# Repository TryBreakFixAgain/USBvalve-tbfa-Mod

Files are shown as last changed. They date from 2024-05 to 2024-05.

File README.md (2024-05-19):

### *USBvalve TBFA Mod*

Based on [cecio/USBvalve](https://github.com/cecio/USBvalve) Version 0.18.0

[**For basic information, please visit the cecio repository.**](https://github.com/cecio/USBvalve)

<br>

I made some modifications to the USBvalve to fulfil the needs of my friends and myself.<br>
To enable **SD-Card Logging**, the entire serial output was redirected.<br>
In addition, there is the comfortable indication via a Ws2812b LED in a **Traffic Light System**.<br>
Additional you can create an independent system with a **Pimoroni Pico Lipo** and the LiPo-Mod.<br>
To ensure complete wireless debugging, the **WiFi HTML Output ESP-01 Mod** is used.<br>
As the PicoW unfortunately does not provide enough RAM, an ESP01 takes over the server tasks.<br>
<br>
Compatibility with the Pi Pico Watch has been removed.

I decided against a custom PCB and used standard components.

**All required parts can be found in the corresponding BOM.**

**You can find pictures in the pictures folder.**
<br>
<br>
**Table of Contents**
* [Mods](#mods)
* [Cases](#cases)
* [Pico Pinout](#pico-pinout)
* [Mappings No Lipo](#mappings-no-lipo)
* [Mappings Pimoroni Pico LiPo](#mappings-lipo-pimoroni-pico-lipo)
* [Additional Mappings SD-Logger](#mappings-sd-logger)
* [Additional Mappings ESP01-Server](#mappings-esp01-server)
* [LED meanings](#led-meanings)
* [Firmware Naming](#firmware-naming)
* [Customize Firmware](#customize-firmware)
* [Dockerfile](#dockerfile)
* [Flash Firmware](#flash-firmware)
* [Safety Warning](#safety-warning)

<br><br>

### *Mods:*
- TrafficLight LED
- simple language customisation
- Fixing the first 2 lines
- LiPo Mod
- SD-Card Logger
- WiFi HTML Output ESP-01 (ESP8266)
- PicoW LED Fix (No-WiFi Support)

**More information can be found on the wiki**

<br><br>

### *Cases:*
STL-Files could be fond in the STL folder.

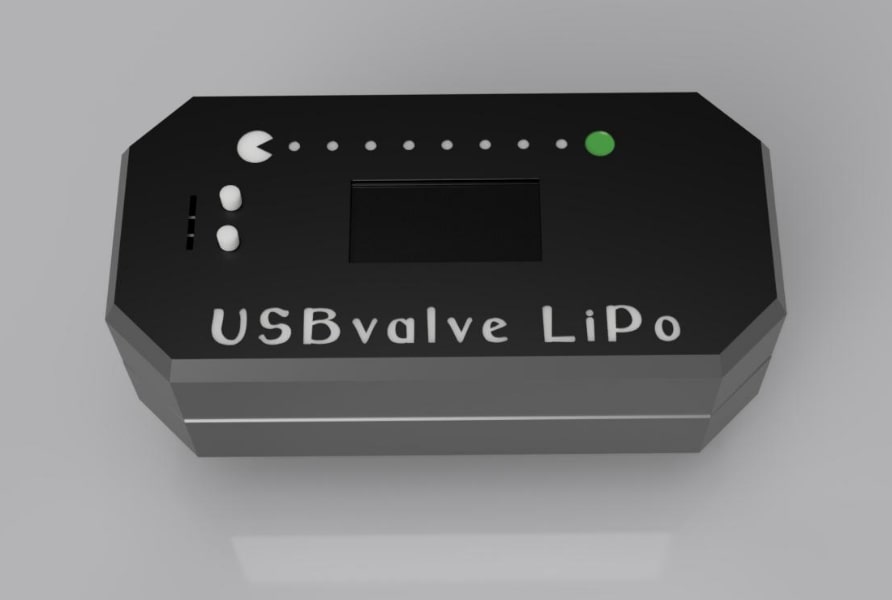
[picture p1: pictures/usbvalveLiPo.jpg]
USBvalve LiPo
> 
> 
> **3D printable case for USBvalve LiPo (FDM ready 0.4 Nozzle)**
> <details> 
> <summary>My Settings</summary> 
>  
> **LipoValveBottom.stl & LipoValveBottom.stl**
> 
> - No supports
> - Layer height first and secound Layer 0.1 after it 0.2
> 
> **LipoValveInner.stl**
> 
> - Supports
> - Layer height 0.2
> 
> **2x LipoValveButton.stl**
> 
> - No supports
> - Raft
> - Layer height 0.2
>  
> </details>

<br>
  
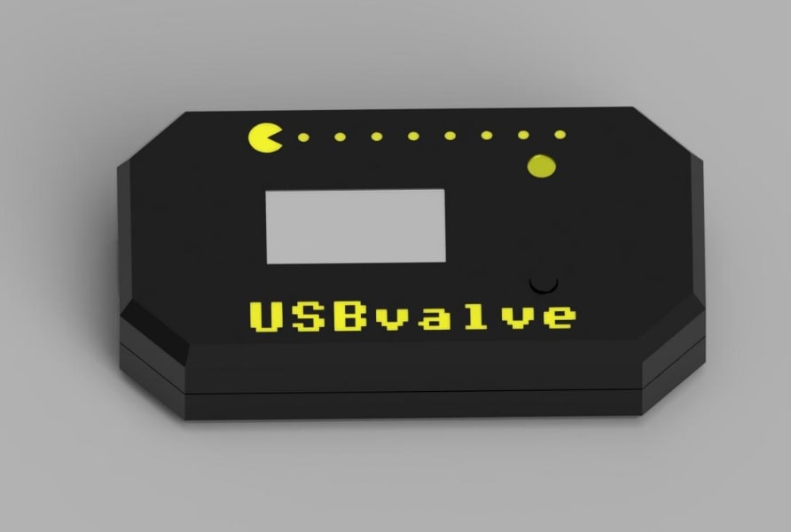
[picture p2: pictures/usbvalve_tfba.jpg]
USBvalve tbfa
>
> 
> **3D printable case for USBvalve none custom PCB (FDM ready 0.4 Nozzle)**
> <details> 
> <summary>My Settings</summary> 
>  
> - No supports
> - Layer height first and secound Layer 0.1 after it 0.2
>
> </details>

<br><br>
### *Pico Pinout:*
USBvalve tbfa
<br><br>

### *Mappings NO LiPo:*
> - PIN6 (GPIO4) of Pi --> OLED SDA
> - PIN7 (GPIO5) of Pi --> OLED SCL
> - PIN19 (GPIO14) of Pi --> D+ of USB Host
> - PIN20 (GPIO15) of Pi --> D- of USB Host
> - PIN23 (GND) of Pi --> GND of USB Host
> - PIN38 (GND) of Pi --> OLED GND
> - PIN36 (3V3OUT) of Pi --> OLED VCC
> - PIN40 (VBUS) of Pi --> VCC of USB Host
>   
> TrafficLight
> I use 3.3V to power the LED because 5V was too bright for me.
> Depending on the LED you may have to use 5V.
> 
> - PIN36 (3V3OUT) of Pi --> OLED VCC OR PIN40 (VBUS) of Pi --> VCC of Ws2812b DOT
> - PIN28 (GND) of Pi --> GND of Ws2812b DOT
> - PIN10 (GPIO7) of Pi --> DIN of Ws2812b DOT
>  
> Additional BOOTSEL Button form my Case Design
> - TP6 of Pi (Bottom side Testpoint) --> Pushbutton
> - PIN28 (GND) of Pi --> Pushbutton
> 

<br><br>
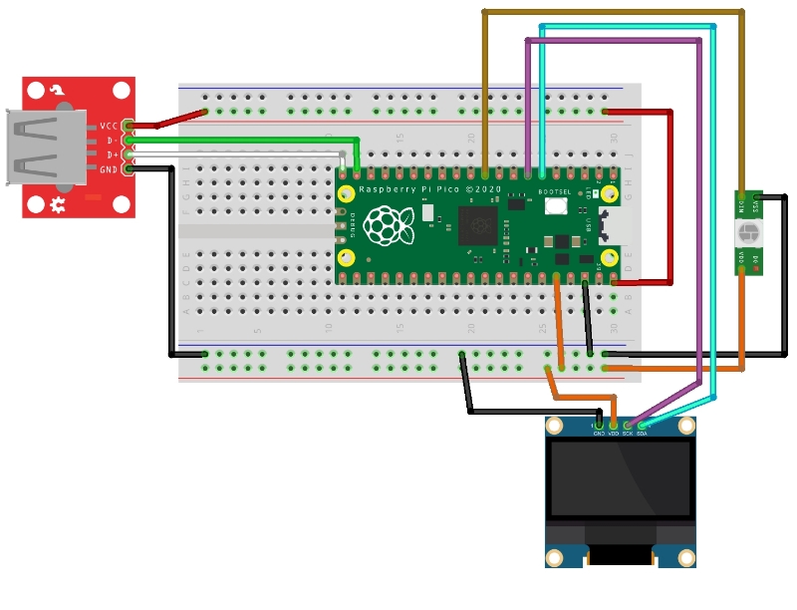
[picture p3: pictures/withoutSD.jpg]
USBvalve tbfa without SD

<br><br>

### *Mappings LiPo (Pimoroni Pico LiPo):*
> - PIN6 (GPIO4) of Pi --> OLED SDA
> - PIN7 (GPIO5) of Pi --> OLED SCL
> - PIN19 (GPIO14) of Pi --> D+ of USB Host
> - PIN20 (GPIO15) of Pi --> D- of USB Host
> - PIN38 (GND) of Pi --> OLED GND
> - PIN36 (3V3OUT) of Pi --> OLED VCC
> - PIN39 (VSYS) of Pi --> + IN DC-DC  3.7V to 5V Step-Up
> - PIN23 (GND) of Pi --> - IN DC-DC  3.7V to 5V Step-Up
> - \+ OUT DC-DC  3.7V to 5V Step-Up --> VCC of USB Host
> - \- OUT DC-DC  3.7V to 5V Step-Up --> GND of USB Host
>   
> TrafficLight
> I use 3.3V to power the LED because 5V was too bright for me.
> Depending on the LED you may have to use 5V.
> 
> - PIN36 (3V3OUT) of Pi --> OLED VCC OR PIN40 (VBUS) of Pi --> VCC of Ws2812b DOT
> - PIN28 (GND) of Pi --> GND of Ws2812b DOT
> - PIN10 (GPIO7) of Pi --> DIN of Ws2812b DOT
> 

<br><br>

### *Mappings SD-Logger:*
> SPI MicroSD Breakout Adapter
>
> - PIN21 (GPIO16) of Pi --> SD-Card Breakout MISO 
> - PIN22 (GPIO17) of Pi --> SD-Card Breakout CS
> - PIN24 (GPIO18) of Pi --> SD-Card Breakout SCK
> - PIN25 (GPIO19) of Pi --> SD-Card Breakout MOSI
> - PIN33 (GND) of Pi --> OLED GND
> - PIN36 (3V3OUT) of Pi --> OLED VCC
> 

<br><br>
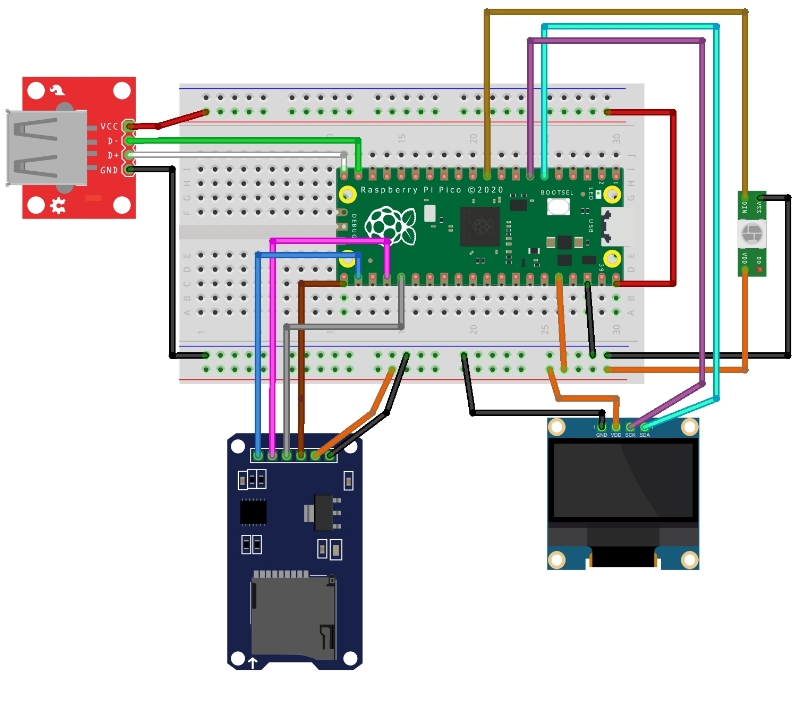
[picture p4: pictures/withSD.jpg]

<br><br>

<br><br>

### *Mappings ESP01-Server:*
> ESP01 (ESP8266) Server
>
> - PIN11 (GPIO8) of Pi --> RX of ESP01 
> - PIN12 (GPIO9) of Pi --> TX of ESP01 
> - PIN18 (GND) of Pi --> GND  of ESP01
> - PIN36 (3V3OUT) of Pi --> 3.3 VCC of ESP01
> - Push Button --> GPIO0 of ESP01 
> - Push Button --> PIN18 (GND) of Pi
>

<br><br>
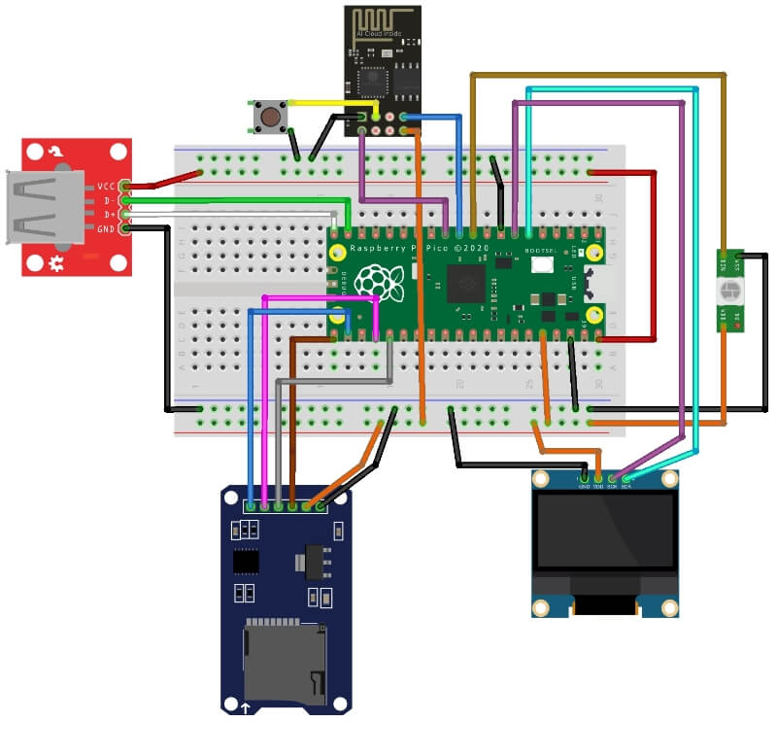
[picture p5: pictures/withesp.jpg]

<br><br>

### *LED meanings:*
- Red: Things are happening that must not happen.
- Green: Everything is OK
- Orange: Attention, something could be wrong.
- Off: Nothing connected or nothing recognised. Attention: The LED remains off with some RubberDuckies. So if a stick is connected and the LED shows nothing, it could be a RubberDucky.

<br><br>

### *Firmware Naming:*
>
>USBvalve_tbfa-x.xx.x-32NoMod = No Mods, 32Pixel Display<br>
>USBvalve_tbfa-x.xx.x-64NoMod = No Mods, 64Pixel Display
>
>USBvalve_tbfa-x.xx.x-32Tr = TrafficLight, 32Pixel Display<br>
>USBvalve_tbfa-x.xx.x-64Tr = TrafficLight, 64Pixel Display
>
>USBvalve_tbfa-x.xx.x-32SdTr = SD-Logger, TrafficLight, 32Pixel Display<br>
>USBvalve_tbfa-x.xx.x-64SdTr = SD-Logger, TrafficLight, 64Pixel Display
>
>USBvalve_tbfa-x.xx.x-32Sd = SD-Logger, 32Pixel Display<br>
>USBvalve_tbfa-x.xx.x-64Sd = SD-Logger, 64Pixel Display
>
>USBvalve_tbfa-x.xx.x-32LiSdTr = LiPo, SD-Logger, TrafficLight, 32Pixel Display<br>
>USBvalve_tbfa-x.xx.x-64LiSdTr = LiPo, SD-Logger, TrafficLight, 64Pixel Display
>
>USBvalve_tbfa-x.xx.x-32LiSd = LiPo, SD-Logger, 32Pixel Display<br>
>USBvalve_tbfa-x.xx.x-64LiSd = LiPo, SD-Logger, 64Pixel Display
>
>USBvalve_tbfa-x.xx.x-32LiTr = LiPo, TrafficLight, 32Pixel Display<br>
>USBvalve_tbfa-x.xx.x-64LiTr = LiPo, TrafficLight, 64Pixel Display
>
>USBvalve_tbfa-x.xx.x-32Li = LiPo, 32Pixel Display<br>
>USBvalve_tbfa-x.xx.x-64Li = LiPo, 32Pixel Display
>
>USBvalve_tbfa-x.xx.x-32Wi = WiFi, 32Pixel Display<br>
>USBvalve_tbfa-x.xx.x-64Wi = WiFi, 64Pixel Display
>
>USBvalve_tbfa-x.xx.x-32SdTrWI = SD-Logger, TrafficLight, WiFi, 32Pixel Display<br>
>USBvalve_tbfa-x.xx.x-64SdTrWI = SD-Logger, TrafficLight, WiFi, 64Pixel Display
>
>USBvalve_tbfa-x.xx.x-32SdWI = SD-Logger, WiFi, 32Pixel Display<br>
>USBvalve_tbfa-x.xx.x-64SdWI = SD-Logger, WiFi, 64Pixel Display
>
>USBvalve_tbfa-x.xx.x-32LiSdTrWI = LiPo, SD-Logger, TrafficLight, WiFi, 32Pixel Display<br>
>USBvalve_tbfa-x.xx.x-64LiSdTrWI = LiPo, SD-Logger, TrafficLight, WiFi, 64Pixel Display
>
>USBvalve_tbfa-x.xx.x-32LiSdWI = LiPo, SD-Logger, WiFi, 32Pixel Display<br>
>USBvalve_tbfa-x.xx.x-64LiSdWI = LiPo, SD-Logger, WiFi, 64Pixel Display
>
>USBvalve_tbfa-x.xx.x-32LiTrWI = LiPo, TrafficLight, WiFi, 32Pixel Display<br>
>USBvalve_tbfa-x.xx.x-64LiTrWI = LiPo, TrafficLight, WiFi, 64Pixel Display
>
>USBvalve_tbfa-x.xx.x-32LiWI = LiPo, WiFi, 32Pixel Display<br>
>USBvalve_tbfa-x.xx.x-64LiWI = LiPo, WiFi, 32Pixel Display
>

<br><br>
### *Customize Firmware:*
You can build your own firmware.

**Uncomment one ore more defines to compile the MODS you want to use.**
```
/* 
 * #define TBFA_TRAFFIC = TrafficLight Mod
 * #define TBFA_LIPO = Pimoroni Pico LiPo Battery Mod
 * #define TBFA_SDLOG = SD-CARD Logger Mod
 * #define TBFA_ONBORDLED = Use Onbord LED on Pico
 * #define TBFA_ONBORDLEDW = Use Onbord LED on PicoW
 * #define TBFA_ESP01SRV = Use ESP01 as Webserver
 */

//#define TBFA_TRAFFIC
//#define TBFA_LIPO
//#define TBFA_SDLOG
//#define TBFA_ONBORDLED
//#define TBFA_ONBORDLEDW
//#define TBFA_ESP01SRV
```
<br>
To build the standard one I used:

- Arduino IDE 2.3.2
- Adafruit TinyUSB Library version 3.1.4, Pico-PIO-USB version 0.5.2, Board Raspberry Pi RP2040 (3.8.0) setting Tools=>CPU Speed at 120MHz and Tools=>USB Stack to Adafruit TinyUSB
- Adafruit_SSD1306 OLED library version 2.5.10
- ArduinoJson 7.0.4
- Adafruit NeoPixel 1.12.2
- SD by Arduino, Sparkfun 1.2.4

**Information on customising the ESP01 firmware can be found in the wiki**

<br><br>

### *Dockerfile:*

If you want to build your own firmware, after you customized it, I provide a Dockerfile which builds a complete Arduino environment and compile the firmware. Enter the following commands in the main USBvalve_tbfa folder:

```
docker build -t usbvalve_tbfa/arduino-cli .
docker run --rm --name usbvalve_tbfa -v $PWD:/mnt usbvalve_tbfa/arduino-cli /mnt/USBvalve_tbfa 
```

The firmware will be placed with extension uf2 in folder USBvalve_tbfa_out.

<br><br>

### *Flash Firmware:*

To flash the firmware, follow these steps:

- Connect the Raspberry Pi Pico with the USB cable, by keeping the BOOTSEL button pressed (the big white button on the board)
- release the button
- you will see a new drive on the system, named RPI-RP2 (in Linux envs you may have to manually mount it)
- copy the proper firmware file (with extension uf2) in the folder, depending on the OLED you used
- wait few seconds until the mounted folder disappear

It's done!

**Information on flashing the ESP01 can be found in the wiki**

<br><br>

### *SAFETY WARNING:*

> [!WARNING]
> I've received a lot of questions about **USBvalve** and *USB killer devices*. **USBvalve** is not built to test these devices, it has not any kind of insulation or protection, so if you have the suspect you are dealing with one of these devices, test it with something else, NOT with **USBvalve** or you may damage the device, yourself or objects near to you.

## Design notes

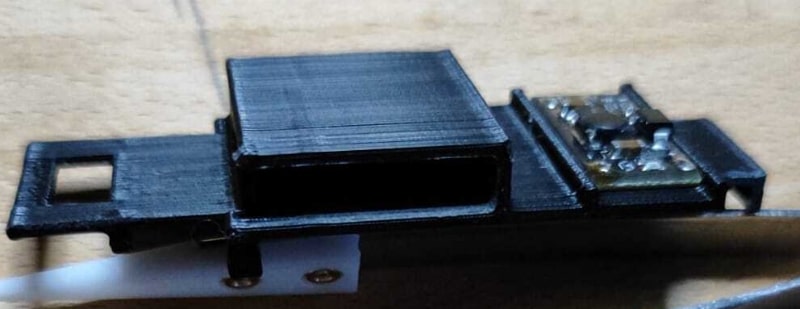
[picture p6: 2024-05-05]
pictures/usbvalvelipo05.jpg

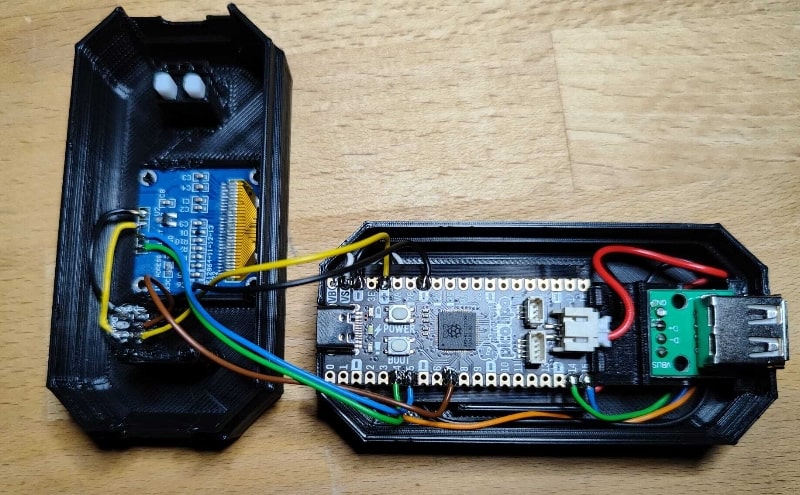
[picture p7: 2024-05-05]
pictures/usbvalvelipo09.jpg

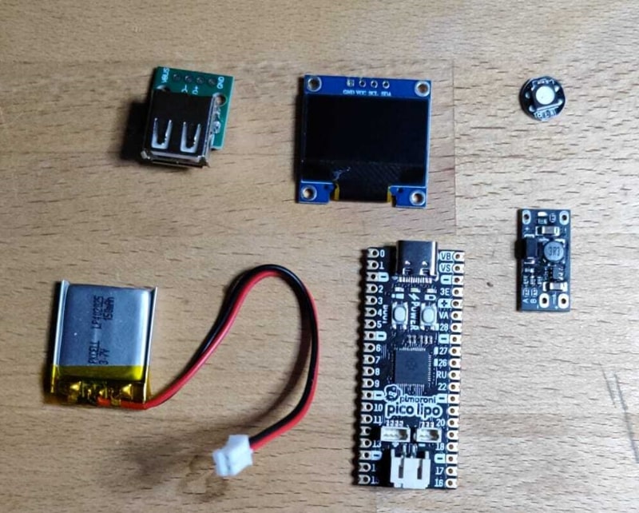
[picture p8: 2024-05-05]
pictures/usbvalvelipo01.jpg

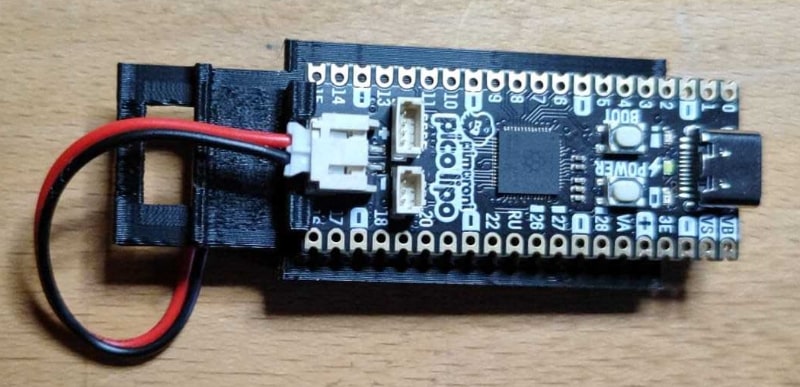
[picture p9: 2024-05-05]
pictures/usbvalvelipo07.jpg

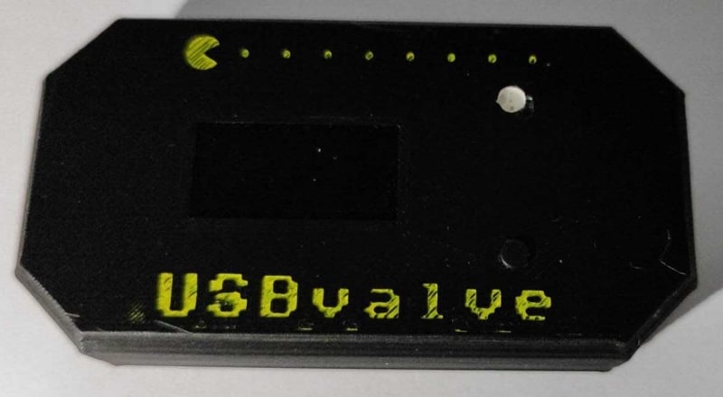
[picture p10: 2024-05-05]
pictures/usbvalve01.jpg

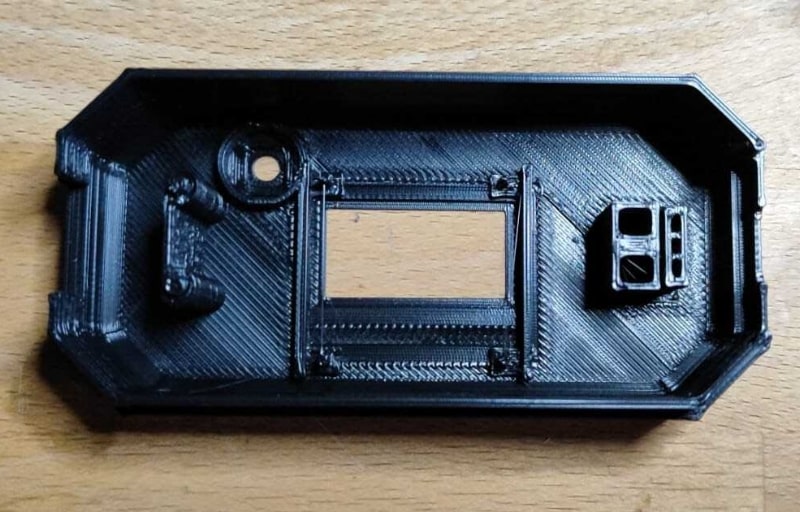
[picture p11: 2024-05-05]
pictures/usbvalvelipo02.jpg

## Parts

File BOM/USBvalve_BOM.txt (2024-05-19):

Raspberry Pico:		https://www.amazon.com/dp/B0BK9CTMSV

Display SSD1306 I2C	https://www.amazon.com/dp/B0BWJFVYZR

USB-Connector:		https://www.amazon.com/dp/B07VBRTDVF

Pushbutton:		https://www.amazon.com/dp/B01CGMP9GY

Additional:
WS2812B DOT:		https://www.amazon.com/dp/B01DC0J3UM  for TrafficLight Mod

SPI SD-Card Adapter	https://www.amazon.com/dp/B08C4WY2WR  for  SD-Logger

Pushbutton:		https://www.amazon.com/dp/B01CGMP9GY  for  WiFi HTML Output ESP-01

ESP01 (ESP8266)	https://www.amazon.com/dp/B010N1ROQS  for  WiFi HTML Output ESP-01

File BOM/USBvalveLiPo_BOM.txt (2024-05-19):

Pimoroni Pico LiPo:	https://shop.pimoroni.com/products/pimoroni-pico-lipo

LiPo LP402025 +3.7V 150mAh:  https://shop.pimoroni.com/products/lipo-battery-pack?variant=20429081991

Display SSD1306 I2C	https://www.amazon.com/dp/B0BWJFVYZR

USB-Connector:		https://www.amazon.com/dp/B07VBRTDVF

Additional:
WS2812B DOT:		https://www.amazon.com/dp/B01DC0J3UM  for TrafficLight Mod

SPI SD-Card Adapter	https://www.amazon.com/dp/B08C4WY2WR  for  SD-Logger

Pushbutton:		https://www.amazon.com/dp/B01CGMP9GY  for  WiFi HTML Output ESP-01

ESP01 (ESP8266)	https://www.amazon.com/dp/B010N1ROQS  for  WiFi HTML Output ESP-01

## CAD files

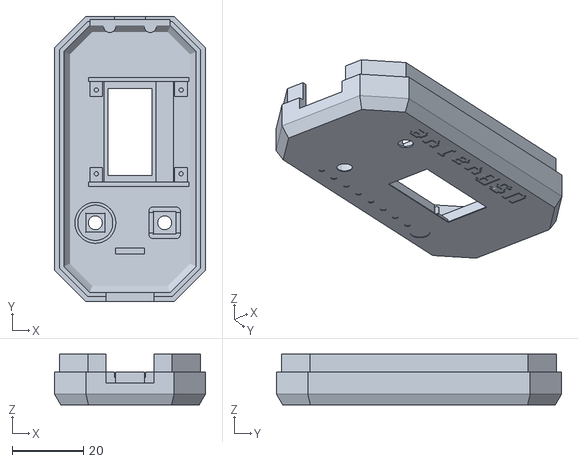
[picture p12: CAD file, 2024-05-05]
STL/USBvalve/USBvalveTop.stl
42.4 x 80.0 x 14.2

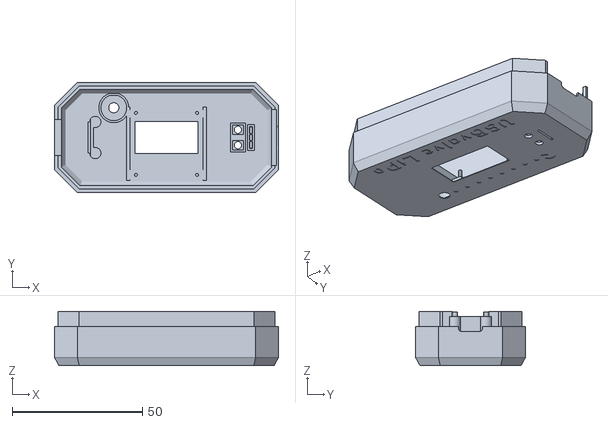
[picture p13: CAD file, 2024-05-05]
STL/USBvalveLiPo/LiPoValveTop.stl
86.1 x 42.3 x 20.8

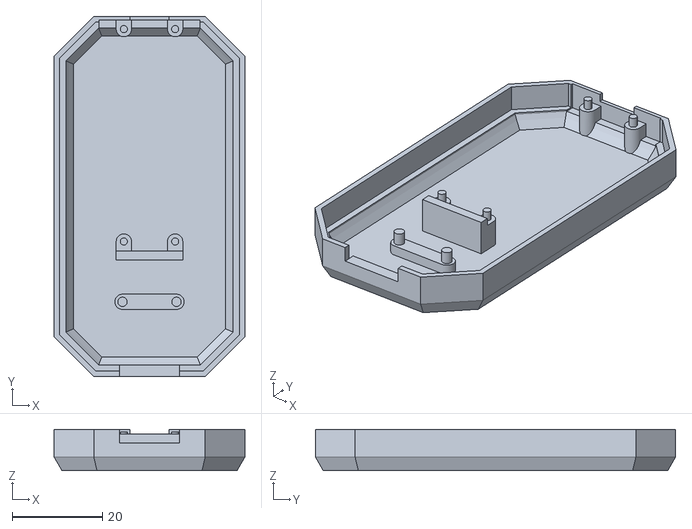
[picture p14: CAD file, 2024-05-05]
STL/USBvalve/USBvalveBottom.stl
42.4 x 80.0 x 9.20

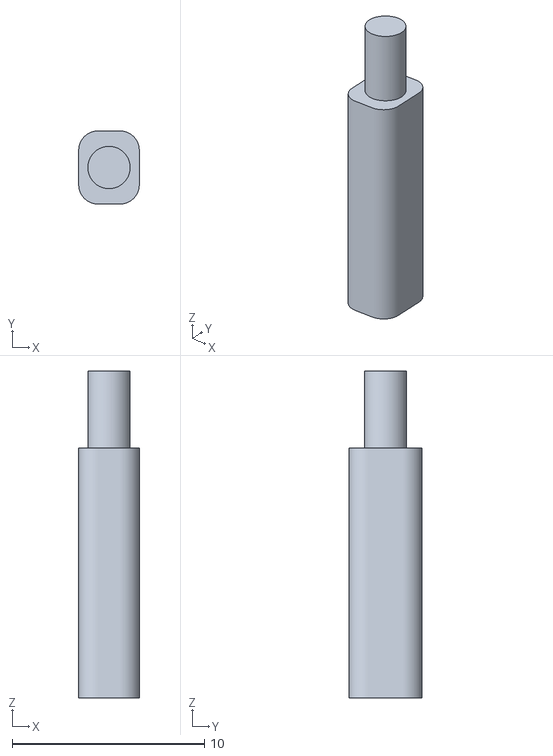
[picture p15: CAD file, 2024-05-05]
STL/USBvalveLiPo/LiPoValveButtons.stl
3.15 x 3.80 x 17.0

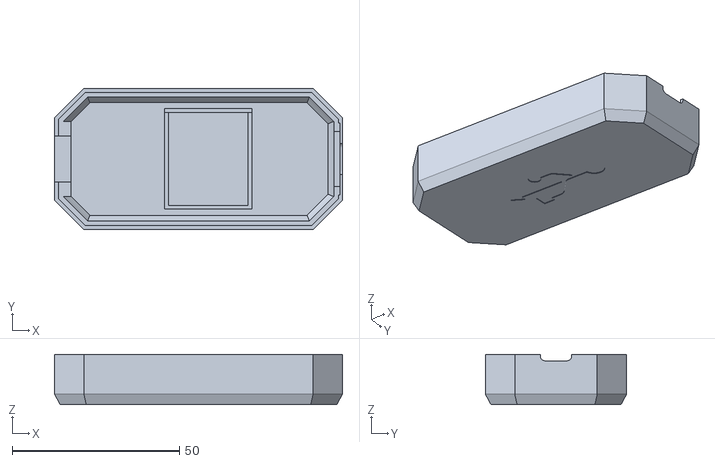
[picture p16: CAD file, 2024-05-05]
STL/USBvalveLiPo/LiPoValveBottom.stl
86.1 x 42.3 x 15.0

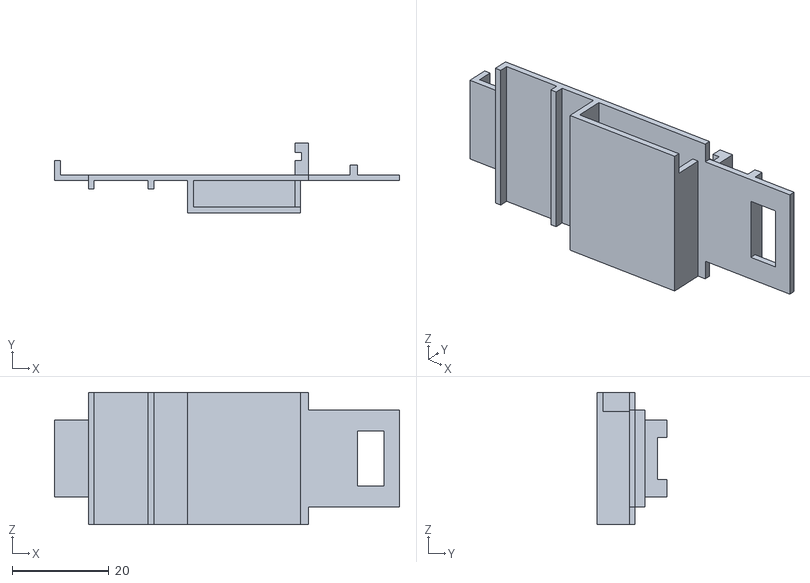
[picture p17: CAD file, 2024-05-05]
STL/USBvalveLiPo/LiPoValveInner.stl
71.5 x 14.5 x 27.4

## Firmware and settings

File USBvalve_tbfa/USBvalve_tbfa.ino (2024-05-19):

/*********************************************************************

  USBvalve TryBreakFixAgain MOD (Trafficlight)
  
  Original written by Cesare Pizzi
  https://github.com/cecio/USBvalve
  It�s a nice Guy!

  All changes can be found via tbfa and TryBreakFixAgain
  
*********************************************************************/

/*********************************************************************

  USBvalve
  
  written by Cesare Pizzi
  This project extensively reuse code done by Adafruit and TinyUSB. 
  Please support them!

*********************************************************************/

/*********************************************************************
  Adafruit invests time and resources providing this open source code,
  please support Adafruit and open-source hardware by purchasing
  products from Adafruit!

  MIT license, check LICENSE for more information
  Copyright (c) 2019 Ha Thach for Adafruit Industries
  All text above, and the splash screen below must be included in
  any redistribution
*********************************************************************/


// Uncomment one ore more defines to compile the MODS you want to use

/* 
 * #define TBFA_TRAFFIC = TrafficLight Mod
 * #define TBFA_LIPO = Pimoroni Pico LiPo Battery Mod
 * #define TBFA_SDLOG = SD-CARD Logger Mod
 * #define TBFA_ONBORDLED = Use Onbord LED on Pico
 * #define TBFA_ONBORDLEDW = Use Onbord LED on PicoW
 * #define TBFA_ESP01SRV = Use ESP01 as Webserver
 */

//#define TBFA_TRAFFIC
//#define TBFA_LIPO
//#define TBFA_SDLOG
//#define TBFA_ONBORDLED
//#define TBFA_ONBORDLEDW
//#define TBFA_ESP01SRV

#include <pio_usb.h>
#include "Adafruit_TinyUSB.h"
#include <XxHash_arduino.h>
#include <pico/stdlib.h>
#include <SPI.h>
#include <Wire.h>
#include <Adafruit_GFX.h>
#include <Adafruit_SSD1306.h>

#if defined(TBFA_ONBORDLED)
// LED Pin. If solid GREEN everything is OK, otherwise it will be put OFF
#define LED_PIN   25
#endif

// START TryBreakFixAgain MODS

/* TryBreakFixAgain Language MOD
 * Using Json for later modifications
 * definition in setup
 * rebuilded the printout()
 * variables, functions ... use the prefix tbfa_
 */

#include <ArduinoJson.h>
JsonDocument tbfa_dictonary;
char bufferx[200];

#if defined(TBFA_TRAFFIC)
/* TryBreakFixAgain TrafficLight MOD
 * Using a Ws2812b DOT (https://www.amazon.com/dp/B088K8DVMQ) ON Pin 10 (GPIO7)
 * Powerd on 3.3V at 5v the brightness is too high for me
 *
 * All TrafficLight Functions at the end of file.
 * config in setup()
 */

#include <NeoPixelConnect.h>
#define tbfa_PixelPin 7 // PixelData Pin
#define tbfa_PixelNum 1 // Pixel count
NeoPixelConnect pixels(tbfa_PixelPin, tbfa_PixelNum, pio0, 1);
//Set and Protect LED Status
boolean tbfa_lightbreak = false;
int tbfa_lightstatus = 0;
#endif

#if defined(TBFA_LIPO)
/* TryBreakFixAgain LiPo MOD
 * Using a Pimoroni Pico LiPo https://shop.pimoroni.com/products/pimoroni-pico-lipo 
 * Battery status on GPIO29 /  GPIO24 status if USB is connected or not
 * change tbfa_full_battery and tbfa_empty_battery to your Battery
 * Using a LP402025 +3.7V 150mAh https://shop.pimoroni.com/products/lipo-battery-pack?variant=20429081991
 */
const int tbfa_batPin = 29;
const int tbfa_usbPower = 24;
int tbfa_batValue = 0;
float tbfa_conversion_factor = 3 * 3.3 / 65535;
float tbfa_full_battery = 4.2;
float tbfa_empty_battery = 3.4;
int tbfa_charging = 0;
int tbfa_batcount = 0;
boolean tbfa_jumpbat = false;
#endif


#if defined(TBFA_SDLOG)
/* TryBreakFixAgain SD-CARD Logger MOD
 * Using a Waveshare Micro SD Board https://www.amazon.com/dp/B00KM6WO0Q
 */
const int _MISO = 16;  // AKA SPI RX
const int _MOSI = 19;  // AKA SPI TX
const int _SCK = 18;
const int _CS = 17;
#include <SD.h>
File dataLog;
#endif

// END TryBreakFixAgain MODS

//
// BADUSB detector section
//

/*
 * Requirements:
 * - [Pico-PIO-USB](https://github.com/sekigon-gonnoc/Pico-PIO-USB) library
 * - 2 consecutive GPIOs: D+ is defined by HOST_PIN_DP (gpio2), D- = D+ +1 (gpio3)
 * - CPU Speed must be either 120 or 240 Mhz. Selected via "Menu -> CPU Speed"
 */

#define HOST_PIN_DP 14      // Pin used as D+ for host, D- = D+ + 1
#define LANGUAGE_ID 0x0407  // English

// USB Host object
Adafruit_USBH_Host USBHost;

// END of BADUSB detector section


#define I2C_ADDRESS 0x3C  // 0X3C+SA0 - 0x3C or 0x3D
#define RST_PIN -1        // Define proper RST_PIN if required.
#define OLED_WIDTH  128
#define OLED_HEIGHT 32    // 64 or 32 depending on the OLED

Adafruit_SSD1306 display(OLED_WIDTH, OLED_HEIGHT, &Wire, RST_PIN);


// Define the dimension of RAM DISK. We have a "real" one (for which
// a real array is created) and a "fake" one, presented to the OS
#define DISK_BLOCK_NUM 0x150
#define FAKE_DISK_BLOCK_NUM 0x800
#define DISK_BLOCK_SIZE 0x200
#include "ramdisk.h"

Adafruit_USBD_MSC usb_msc;

// Eject button to demonstrate medium is not ready e.g SDCard is not present
// whenever this button is pressed and hold, it will report to host as not ready
#if defined(ARDUINO_SAMD_CIRCUITPLAYGROUND_EXPRESS) || defined(ARDUINO_NRF52840_CIRCUITPLAY)
#define BTN_EJECT 4  // Left Button
bool activeState = true;

#elif defined(ARDUINO_FUNHOUSE_ESP32S2)
#define BTN_EJECT BUTTON_DOWN
bool activeState = true;

#elif defined PIN_BUTTON1
#define BTN_EJECT PIN_BUTTON1
bool activeState = false;
#endif

//
// USBvalve globals
//
#define VERSION "USBvalve-0.18.3 Mod"
boolean readme = false;
boolean autorun = false;
boolean written = false;
boolean deleted = false;
boolean written_reported = false;
boolean deleted_reported = false;
boolean hid_sent = false;
boolean hid_reported = false;

//
// Anti-Detection settings.
//
// Set USB IDs strings and numbers, to avoid possible detections.
// Remember that you can cusotmize FAKE_DISK_BLOCK_NUM as well
// for the same reason. Also DISK_LABEL in ramdisk.h can be changed.
//
// You can see here for inspiration: https://the-sz.com/products/usbid/
//
// Example:
//             0x0951 0x16D5    VENDORID_STR: Kingston   PRODUCTID_STR: DataTraveler
//
#define USB_VENDORID 0x0951               // This override the Pi Pico default 0x2E8A
#define USB_PRODUCTID 0x16D5              // This override the Pi Pico default 0x000A
#define USB_DESCRIPTOR "DataTraveler"     // This override the Pi Pico default "Pico"
#define USB_MANUF "Kingston"              // This override the Pi Pico default "Raspberry Pi"
#define USB_SERIAL "123456789A"           // This override the Pi Pico default. Disabled by default. \
                                          // See "setSerialDescriptor" in setup() if needed
#define USB_VENDORID_STR "Kingston"       // Up to 8 chars
#define USB_PRODUCTID_STR "DataTraveler"  // Up to 16 chars
#define USB_VERSION_STR "1.0"             // Up to 4 chars

#define BLOCK_AUTORUN 102       // Block where Autorun.inf file is saved
#define BLOCK_README 100        // Block where README.txt file is saved
#define MAX_DUMP_BYTES 16       // Used by the dump of the debug facility: do not increase this too much
#define BYTES_TO_HASH 512 * 2   // Number of bytes of the RAM disk used to check consistency
#define BYTES_TO_HASH_OFFSET 7  // Starting sector to check for consistency (FAT_DIRECTORY is 7)

// Burned hash to check consistency
uint valid_hash = 2362816530;

// Core 0 Setup: will be used for the USB mass device functions
void setup() {
  // START TryBreakFixAgain Language definitions
  tbfa_dictonary["selfok"][0] ="[+] Selftest: OK";
  tbfa_dictonary["selfko"][0] ="[!] Selftest: KO";
  tbfa_dictonary["stop"][0] ="[!] Stopping...";
  tbfa_dictonary["readme"][0] ="[!] README (R)";
  tbfa_dictonary["autorun"][0] ="[+] AUTORUN (R)";
  tbfa_dictonary["deleting"][0] = "[!] DELETING";
  tbfa_dictonary["write"][0] ="[!] WRITING";
  tbfa_dictonary["hidsend"][0] ="[!!] HID Sending data";
  tbfa_dictonary["reset"][0] ="[+] RESETTING";
  tbfa_dictonary["hiddev"][0] ="[!!] HID Device";
  tbfa_dictonary["massdev"][0] ="[++] Mass Device";
  tbfa_dictonary["cdcdev"][0] ="[++] CDC Device";
  tbfa_dictonary["version"][0] =VERSION;
  tbfa_dictonary["cardok"][0] ="[+] SD OK";
  tbfa_dictonary["cardko"][0] ="[!] SD ERROR";
  tbfa_dictonary["bigfile"][0] ="[!] BIG LOG";
  tbfa_dictonary["espip"][0] ="";
  // END TryBreakFixAgain Language definitions

#if defined(TBFA_TRAFFIC)
  // START TryBreakFixAgain Trafficlight definitions
  // values as integer 0= Off, 1=Blue , 2=Green , 3=Orange 4=Red
  tbfa_dictonary["selfok"][1] = 2;
  tbfa_dictonary["selfko"][1] = 4;
  tbfa_dictonary["stop"][1] = 4;
  tbfa_dictonary["readme"][1] = 3;
  tbfa_dictonary["autorun"][1] = 2;
  tbfa_dictonary["deleting"][1] = 3;
  tbfa_dictonary["write"][1] =" 3";
  tbfa_dictonary["hidsend"][1] = 4;
  tbfa_dictonary["reset"][1] = 0;
  tbfa_dictonary["hiddev"][1] = 4;
  tbfa_dictonary["massdev"][1] = 2;
  tbfa_dictonary["cdcdev"][1] = 2;
  tbfa_dictonary["version"][1] = 0;
  tbfa_dictonary["cardok"][1] = 0;
  tbfa_dictonary["cardko"][1] = 0;
  tbfa_dictonary["bigfile"][1] = 3;
  tbfa_dictonary["espip"][1] = "1";
  // END TryBreakFixAgain Language definitions
#endif

#if defined(TBFA_LIPO)
  // START TryBreakFixAgain Battery readings config
  analogReadResolution(16);
  pinMode(tbfa_usbPower, INPUT);
  // END TryBreakFixAgain Battery readings config
#endif

  // Change all the USB Pico settings
  TinyUSBDevice.setID(USB_VENDORID, USB_PRODUCTID);
  TinyUSBDevice.setProductDescriptor(USB_DESCRIPTOR);
  TinyUSBDevice.setManufacturerDescriptor(USB_MANUF);
  // This could be used to change the serial number as well
  // TinyUSBDevice.setSerialDescriptor(USB_SERIAL);

#if defined(ARDUINO_ARCH_MBED) && defined(ARDUINO_ARCH_RP2040)
  // Manual begin() is required on core without built-in support for TinyUSB such as
  // - mbed rp2040
  TinyUSB_Device_Init(0);
#endif

  // Set disk vendor id, product id and revision with string up to 8, 16, 4 characters respectively
  usb_msc.setID(USB_VENDORID_STR, USB_PRODUCTID_STR, USB_VERSION_STR);

  // Set disk size (using the "fake" size)
  usb_msc.setCapacity(FAKE_DISK_BLOCK_NUM, DISK_BLOCK_SIZE);

  // Set the callback functions
  usb_msc.setReadWriteCallback(msc_read_callback, msc_write_callback, msc_flush_callback);

  // Set Lun ready (RAM disk is always ready)
  usb_msc.setUnitReady(true);

#ifdef BTN_EJECT
  pinMode(BTN_EJECT, activeState ? INPUT_PULLDOWN : INPUT_PULLUP);
  usb_msc.setReadyCallback(msc_ready_callback);
#endif

  // Check consistency of RAM FS
  // Add 11 bytes to skip the DISK_LABEL from the hashing
  // The startup of the USB has been moved before initialization of the 
  // screen because sometimes it inserts some delay preventing
  // proper initialization of the mass device
  uint computed_hash;
  computed_hash = XXH32(msc_disk[BYTES_TO_HASH_OFFSET] + 11, BYTES_TO_HASH, 0);
  if (computed_hash == valid_hash) {
      usb_msc.begin();
  }

  // Screen Init
#if RST_PIN >= 0
  display.begin(SSD1306_SWITCHCAPVCC, I2C_ADDRESS, RST_PIN);
#else
  display.begin(SSD1306_SWITCHCAPVCC, I2C_ADDRESS);
#endif

  display.setTextSize(1);
  cls();  // Clear display

#if defined(TBFA_ESP01SRV)
  // START TryBreakFixAgain Serial on PIN 8/9
  Serial2.setRX(9);
  Serial2.setTX(8);
  Serial2.begin(115200);
  // END TryBreakFixAgain Serial on PIN 8/9
#endif

#if defined(TBFA_TRAFFIC)
  // START TryBreakFixAgain TrafficLight LED-DEMO
  tbfa_trafficlightstart();
  // END TryBreakFixAgain TrafficLight LED-DEMO
#endif

  // Now outputs the result of the check
  if (computed_hash == valid_hash) {
    printout("selfok");
  } else {
    printout("selfko");
    printout("stop");
    while (1) {
      delay(1000);  // Loop forever
    }
  }

#if defined(TBFA_SDLOG)
  // START TryBreakFixAgain SD-CARD config & check
  SPI.setRX(_MISO);
  SPI.setTX(_MOSI);
  SPI.setSCK(_SCK);
  if (!SD.begin(_CS)) {
    printout("cardko");
    delay(500);
    SerialTinyUSB.println("Card failed, or not present");  
  }else{
    printout("cardok");
    delay(500);
    SerialTinyUSB.println("card initialized.");
    if (SD.exists("datalog.txt")) {
      File fproof;
      fproof=SD.open("datalog.txt");
      if((int)fproof.size() > 5242880){
        printout("bigfile");
        SerialTinyUSB.println("datalog.txt bigger then 5MB.");
      }
      fproof.close();
    }
    tbfa_datalogger("\r\n\r\n----------NEW SESSION----------\r\n\r\n", 0);
  }
  // END TryBreakFixAgain SD-CARD config & check
  
#endif

#if defined(TBFA_ONBORDLED)
  // Set up led PIN
  gpio_init(LED_PIN);
  gpio_set_dir(LED_PIN, GPIO_OUT);
  gpio_put(LED_PIN, 1);
#endif

#if defined(TBFA_ONBORDLEDW)
  // Set up led PIN PicoW
  pinMode(LED_BUILTIN, OUTPUT);
  digitalWrite(LED_BUILTIN, HIGH);
#endif

}

// Core 1 Setup: will be used for the USB host functions for BADUSB detector
void setup1() {
  // Set a custom clock (multiple of 12Mhz) to achieve maximum compatibility for HID
  set_sys_clock_khz(144000, true);

  pio_usb_configuration_t pio_cfg = PIO_USB_DEFAULT_CONFIG;
  pio_cfg.pin_dp = HOST_PIN_DP;
  USBHost.configure_pio_usb(1, &pio_cfg);

  // run host stack on controller (rhport) 1
  // Note: For rp2040 pico-pio-usb, calling USBHost.begin() on core1 will have most of the
  // host bit-banging processing works done in core1
  USBHost.begin(1);
}

// Main Core0 loop: managing display
void loop() {

  if (readme == true) {
    printout("readme");
    readme = false;

#if defined(TBFA_ONBORDLED)
    gpio_put(LED_PIN, 0);         // Turn Off LED
#endif
#if defined(TBFA_ONBORDLEDW)
    digitalWrite(LED_BUILTIN, LOW);         // Turn Off LED
#endif

  }

  if (autorun == true) {
    printout("autorun");
    autorun = false;
  }

  if (deleted == true && deleted_reported == false) {
    printout("deleting");
    deleted = false;
    deleted_reported = true;

#if defined(TBFA_ONBORDLED)
    gpio_put(LED_PIN, 0);         // Turn Off LED
#endif
#if defined(TBFA_ONBORDLEDW)
    digitalWrite(LED_BUILTIN, LOW);         // Turn Off LED
#endif

  }

  if (written == true && written_reported == false) {
    printout("write");
    written = false;
    written_reported = true;

#if defined(TBFA_ONBORDLED)
    gpio_put(LED_PIN, 0);         // Turn Off LED
#endif
#if defined(TBFA_ONBORDLEDW)
    digitalWrite(LED_BUILTIN, LOW);         // Turn Off LED
#endif

  }

  if (hid_sent == true && hid_reported == false) {
    printout("hidsend");
    hid_sent = false;
    hid_reported = true;

#if defined(TBFA_ONBORDLED)
    gpio_put(LED_PIN, 0);         // Turn Off LED
#endif
#if defined(TBFA_ONBORDLEDW)
    digitalWrite(LED_BUILTIN, LOW);         // Turn Off LED
#endif

  }

  if (BOOTSEL) {
    printout("reset");
#if defined(TBFA_ESP01SRV)
  // END TryBreakFixAgain Serial on PIN 8/9
    Serial2.println("ESPRESET");
  // END TryBreakFixAgain Serial on PIN 8/9
#endif
    swreset();
  }
#if defined(TBFA_LIPO)
// START TryBreakFixAgain Battery check
  tbfa_batteryPack();
// END TryBreakFixAgain Battery check
#endif
#if defined(TBFA_ESP01SRV)
  if (Serial2.available() > 0) {
    String tempser = Serial2.readString();
    if(tempser.indexOf("IP: ") > -1 ){
      String tempser2= tempser.substring(tempser.indexOf("IP: ") +4 );
      tempser2.trim();
      if(tempser2!=""){
        tbfa_dictonary["espip"][0] = tempser2;
        printout("espip");
        tempser2="";
      }
    } 
  }
  // END TryBreakFixAgain Serial on PIN 8/9
#endif
}

// Main Core1 loop: managing USB Host
void loop1() {
  USBHost.task();
}

// Callback invoked when received READ10 command.
// Copy disk's data to buffer (up to bufsize) and
// return number of copied bytes (must be multiple of block size).
// This happens only for the "real" size of disk
int32_t msc_read_callback(uint32_t lba, void* buffer, uint32_t bufsize) {

  // Check for README.TXT
  if (lba == BLOCK_README) {
    readme = true;
  }

  // Check for AUTORUN.INF
  if (lba == BLOCK_AUTORUN) {
    autorun = true;
  }

  // We are declaring a bigger size than what is actually allocated, so
  // this is protecting our memory integrity
  if (lba < DISK_BLOCK_NUM - 1) {
    uint8_t const* addr = msc_disk[lba];
    memcpy(buffer, addr, bufsize);
  }

  tbfa_print(String("Read LBA: "));
  tbfa_print(String(lba));
  tbfa_print(String("   Size: "));
  tbfa_println(String(bufsize));
  if (lba < DISK_BLOCK_NUM - 1) {
    hexDump(msc_disk[lba], MAX_DUMP_BYTES);
  }
  tbfa_flush();

  return bufsize;
}

// Callback invoked when received WRITE10 command.
// Process data in buffer to disk's storage and
// return number of written bytes (must be multiple of block size).
// This happens only for the "real" size of disk
int32_t msc_write_callback(uint32_t lba, uint8_t* buffer, uint32_t bufsize) {

  // Check for file deletion at Block 7
  // The first char of filename is replaced with 0xE5, we are going
  // to check for it
  if (lba == 7) {
    if (buffer[32] == 0xE5 || buffer[64] == 0xE5 || buffer[160] == 0xE5) {
      deleted = true;
    }
  }

  // This check for writing of space. The LBA > 10 is set to avoid some
  // false positives, in particular on Windows Systems
  if (lba > 10) {
    written = true;
  }

  // We are declaring a bigger size than what is actually allocated, so
  // this is protecting our memory integrity
  if (lba < DISK_BLOCK_NUM - 1) {
    // Writing buffer to "disk"
    uint8_t* addr = msc_disk[lba];
    memcpy(addr, buffer, bufsize);
  }

  tbfa_print(String("Write LBA: "));
  tbfa_print(String(lba));
  tbfa_print(String("   Size: "));
  tbfa_println(String(bufsize));
  if (lba < DISK_BLOCK_NUM - 1) {
    hexDump(msc_disk[lba], MAX_DUMP_BYTES);
  }
  tbfa_flush();

  return bufsize;
}

// Callback invoked when WRITE10 command is completed (status received and accepted by host).
// used to flush any pending cache.
void msc_flush_callback(void) {
  // Nothing to do
}

#ifdef BTN_EJECT
// Invoked when received Test Unit Ready command.
// return true allowing host to read/write this LUN e.g SD card inserted
bool msc_ready_callback(void) {
  // button not active --> medium ready
  return digitalRead(BTN_EJECT) != activeState;
}
#endif


void scrollUp(uint8_t pixels) {
  // Read the current content of the display, shift it up by 'pixels' rows
  display.startscrollright(0x00, 0x07); // Dummy values to initiate scroll
  display.stopscroll(); // Immediately stop to manually shift pixels in memory
  // TryBreakFixAgain Mod for Static first Rows set i from 0 to 16
  for (int i = 16; i < display.height() - pixels; i++) {
    for (int j = 0; j < display.width(); j++) {
      uint8_t color = display.getPixel(j, i + pixels);
      display.drawPixel(j, i, color);
    }
  }

  // Clear the freed space after scrolling
  display.fillRect(0, display.height() - pixels, display.width(), pixels, SSD1306_BLACK);
  // Refresh the display to show the changes
  display.display();
}

void checkAndScroll() {
  // Assumes text height of 8 pixels, but check for 16 because newline is not used
  if ((display.getCursorY() + 16) > display.height()) {
    // Scroll up by 8 pixels
    scrollUp(8);
    display.setCursor(0, display.getCursorY() - 8);
  }
}

// START TryBreakFixAgain modifikated printout()
void printout(const char *ctrl)
{
  // TryBreakFixAgain MOD
  // Normal Printout
  if(ctrl != "cls"){
    String str=tbfa_dictonary[ctrl][0];
    checkAndScroll();
    display.println(str);
    tbfa_println(str);
  }else{
    // Printout first 2 Rows on cls();
    display.setCursor(0, 0);
    display.fillRect(0, 0, display.width(), 16, SSD1306_BLACK);
    display.print(String(tbfa_dictonary["version"][0]));
    display.drawLine(0, 10, display.width(), 10, SSD1306_WHITE);
    display.setCursor(0, 16);
  }
  display.display();

#if defined(TBFA_TRAFFIC)
  //START TryBreakFixAgain TrafficLight SETSTATUS
  int tbfa_led=tbfa_dictonary[ctrl][1];
  tbfa_trafficlight(tbfa_led);
  if(tbfa_led == 4){
    tbfa_lightbreak = true;
  }
  if(ctrl == "selfok" || ctrl == "autorun" || ctrl == "espip"){
    delay(2000);
    tbfa_trafficlight(0);
  }
  //END TryBreakFixAgain TrafficLight SETSTATUS 
#endif

}
// END TryBreakFixAgain modifikated printout()


// Clear display
void cls(void) {
  display.clearDisplay();
  display.setTextColor(SSD1306_WHITE);
  display.setCursor(0, 0);
  // TryBreakFixAgain First Two Rows Mod
  printout("cls");
}


// HexDump
void hexDump(unsigned char* data, size_t size) {
  char asciitab[17];
  size_t i, j;
  asciitab[16] = '\0';

  for (i = 0; i < size; ++i) {

    tbfa_print(String(data[i] >> 4, HEX));
    tbfa_print(String(data[i] & 0x0F, HEX));

    if ((data)[i] >= ' ' && (data)[i] <= '~') {
      asciitab[i % 16] = (data)[i];
    } else {
      asciitab[i % 16] = '.';
    }
    if ((i + 1) % 8 == 0 || i + 1 == size) {
      tbfa_print(" ");
      if ((i + 1) % 16 == 0) {
        tbfa_println(asciitab);
      } else if (i + 1 == size) {
        asciitab[(i + 1) % 16] = '\0';
        if ((i + 1) % 16 <= 8) {
          tbfa_print(" ");
        }
        for (j = (i + 1) % 16; j < 16; ++j) {
          tbfa_print("   ");
        }
        tbfa_print("|  ");
        tbfa_println(String(asciitab));
      }
    }
  }
  tbfa_println("");
}

// Reset the Pico
void swreset() {
  watchdog_enable(1500, 1);
  while (1)
    ;
}

//
// BADUSB detector section
//

static uint8_t const keycode2ascii[128][2] = { HID_KEYCODE_TO_ASCII };

// Invoked when device with hid interface is mounted
void tuh_hid_mount_cb(uint8_t dev_addr, uint8_t instance, uint8_t const* desc_report, uint16_t desc_len) {
  uint16_t vid, pid;
  const char* protocol_str[] = { "None", "Keyboard", "Mouse" };

  // Read the HID protocol
  uint8_t const itf_protocol = tuh_hid_interface_protocol(dev_addr, instance);

  tuh_vid_pid_get(dev_addr, &vid, &pid);

  printout("hiddev");
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

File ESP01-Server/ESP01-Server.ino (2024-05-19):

#include <Arduino.h>
#include <ESP8266WiFi.h>
#include <ESPAsyncWebServer.h>
#include <ESPAsyncTCP.h>
#include "LittleFS.h"
#include "webcalls.h"
#define TRIGGER_PIN 0

//#define DEBUGIT

// Create AsyncWebServer object on port 80
AsyncWebServer server(80);

// Search for parameter in HTTP POST request
const char* PARAM_INPUT_1 = "ssid";
const char* PARAM_INPUT_2 = "pass";
const char* PARAM_INPUT_3 = "ip";
const char* PARAM_INPUT_4 = "gateway";
const char* PARAM_INPUT_5 = "reset";

//Variables to save values from HTML form
String ssid;
String pass;
String ip;
String gateway;
String enterPortal;

// File paths to save input values permanently
const char* ssidPath = "/ssid.txt";
const char* passPath = "/pass.txt";
const char* ipPath = "/ip.txt";
const char* gatewayPath = "/gateway.txt";
const char* enterPortalctrl = "/portal.txt";

//IPAddress localIP;
IPAddress localIP(192, 168, 42, 1); // hardcoded

// Set your Gateway IP address
//IPAddress localGateway;
IPAddress localGateway(192, 168, 42, 1); //hardcoded
IPAddress subnet(255, 255, 2550, 0);

// Timer variables
unsigned long previousMillis = 0;
const long interval = 10000;  // interval to wait for Wi-Fi connection (milliseconds)

boolean restart = false;
String incomingSerial = "";
int visitor = 0;

// Initialize LittleFS
void initFS() {
#if defined(DEBUGIT)  
  if (!LittleFS.begin()) {
    Serial.println("An error has occurred while mounting LittleFS");
  }
  else{
    Serial.println("LittleFS mounted successfully");
  }
#else
  LittleFS.begin();
#endif
}

// Read File from LittleFS
String readFile(fs::FS &fs, const char * path){
#if defined(DEBUGIT) 
  Serial.printf("Reading file: %s\r\n", path);
#endif
  File file = fs.open(path, "r");
  if(!file || file.isDirectory()){
#if defined(DEBUGIT)  
    Serial.println("- failed to open file for reading");
#endif
    return String();
  }

  String fileContent;
  while(file.available()){
    fileContent = file.readStringUntil('\n');
    break;
  }
  file.close();
  return fileContent;
}

// Write file to LittleFS
void writeFile(fs::FS &fs, const char * path, const char * message){
#if defined(DEBUGIT)   
  Serial.printf("Writing file: %s\r\n", path);
#endif
  File file = fs.open(path, "w");
  if(!file){
#if defined(DEBUGIT) 
    Serial.println("- failed to open file for writing");
#endif
    return;
  }
#if defined(DEBUGIT) 
  if(file.print(message)){
    Serial.println("- file written");
  } else {
    Serial.println("- frite failed");
  }
#else
file.print(message);
#endif
  file.close();
}

// Initialize WiFi
bool initWiFi() {
  if(enterPortal=="yes"){
    return false;
  }
  if(enterPortal==""){
    writeFile(LittleFS, enterPortalctrl, "no");
    enterPortal="no";
  }
  if(ssid==""){
#if defined(DEBUGIT)
    Serial.println("Undefined SSID");
#endif
    return false;
  }

  WiFi.mode(WIFI_STA);
  if(ip==""){
    WiFi.begin(ssid.c_str(), pass.c_str());
  }else{
    localIP.fromString(ip.c_str());
    localGateway.fromString(gateway.c_str());

    if (!WiFi.config(localIP, localGateway, subnet)){
#if defined(DEBUGIT)
      Serial.println("STA Failed to configure");
#endif
      return false;
    }
    WiFi.begin(ssid.c_str(), pass.c_str());
  }
#if defined(DEBUGIT)
  Serial.println("Connecting to WiFi...");
#endif
  delay(20000);
  if(WiFi.status() != WL_CONNECTED) {
#if defined(DEBUGIT)
    Serial.println("Failed to connect.");
#endif
    return false;
  }
  String outip = WiFi.localIP().toString();
  Serial.println("IP: " + outip);
  return true;
}


void setup() {
  // Serial port for debugging purposes
  Serial.begin(115200);
  pinMode(TRIGGER_PIN, INPUT);
  initFS();
  
  // Load values saved in LittleFS
  ssid = readFile(LittleFS, ssidPath);
  pass = readFile(LittleFS, passPath);
  ip = readFile(LittleFS, ipPath);
  gateway = readFile (LittleFS, gatewayPath);
  enterPortal = readFile (LittleFS, enterPortalctrl);
#if defined(DEBUGIT)
  Serial.println(ssid);
  Serial.println(pass);
  Serial.println(ip);
  Serial.println(gateway);
  Serial.println(enterPortal);
#endif
  if(initWiFi()) {
#if defined(DEBUGIT)
    Serial.println("Setting Static");
#endif
    // Route for root / web page
    // Serial.println("Webportal");
      server.on("/", HTTP_GET, [](AsyncWebServerRequest *request){
        visitor = 1;
        request->send_P(200, PSTR("text/html"), Web_page);
      });
      server.on("/valveout", HTTP_GET, [](AsyncWebServerRequest *request){
        if(incomingSerial != ""){
          request->send(200, "text/plain", String(incomingSerial)+"\n");
          incomingSerial="";
        }
      });
    server.begin();
  }else{
#if defined(DEBUGIT)
    Serial.println("Setting AP (Access Point)");
#endif
    if(enterPortal=="yes"){
      WiFi.softAP("USBvalveConfig", NULL);
      writeFile(LittleFS, enterPortalctrl, "no");
    }else{
      WiFi.softAP("USBvalve", NULL);
    }
      
    WiFi.softAPConfig(localIP, localGateway, subnet);
    IPAddress IP = WiFi.softAPIP();
#if defined(DEBUGIT)
    Serial.print("AP IP address: ");
#endif
    String outip = IP.toString();;
    Serial.println("IP: " + outip);
    // Web Server Root URL

    if(enterPortal=="yes"){
      // Serial.println("Configportal");
      server.on("/", HTTP_GET, [](AsyncWebServerRequest *request){
        request->send_P(200, PSTR("text/html"), config_portal);
      });
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

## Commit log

2024-05-05 first release of Mod
    Cleaning up
    [BOM_USBpipe_Rev1.ods, BOM_USBpipe_Rev1.x.xlsx, Box_USBvalve_1.1.stl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]
2024-05-19 0.18.3 Bugfix
    Bugfix in LiPo Mod
    [USBvalve_tbfa.ino]
